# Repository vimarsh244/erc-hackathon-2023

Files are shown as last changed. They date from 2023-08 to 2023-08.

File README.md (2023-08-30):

# ERC Hackathon 2023 submission

### Mechanical

**Design**:

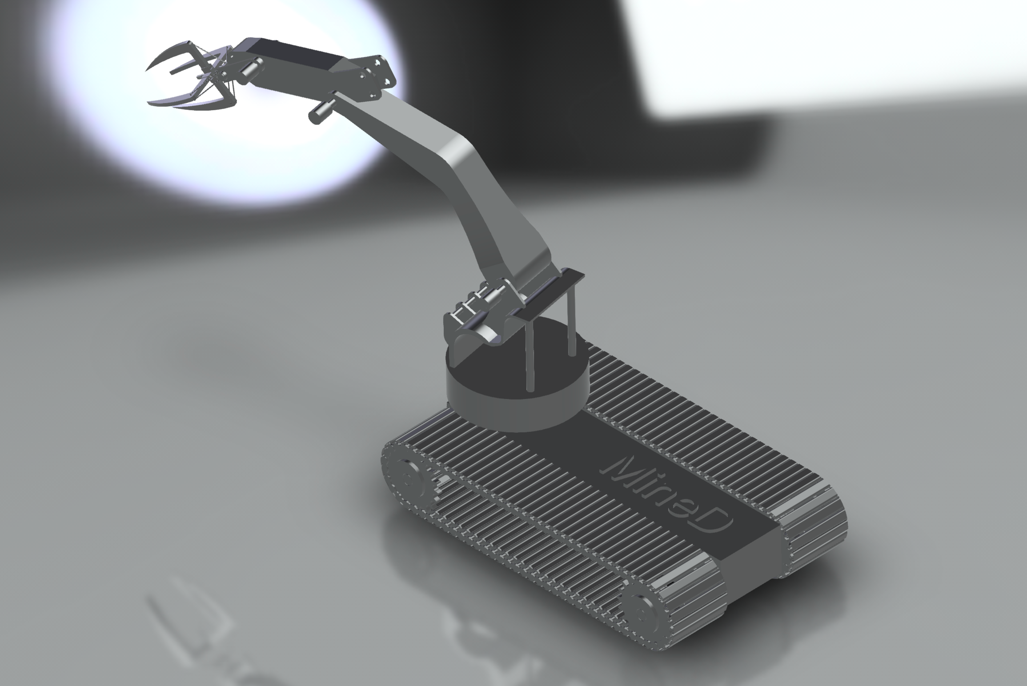
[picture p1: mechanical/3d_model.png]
3D model render


Model files can be found in the `mechanical/` directory or https://a360.co/45wuxL5

**Ansys Analysis**:

Report can be found [here](mechanical/ansys%20analysis/ERC%20HACK%20ANSYS%20MINED.pdf)

### Electronics

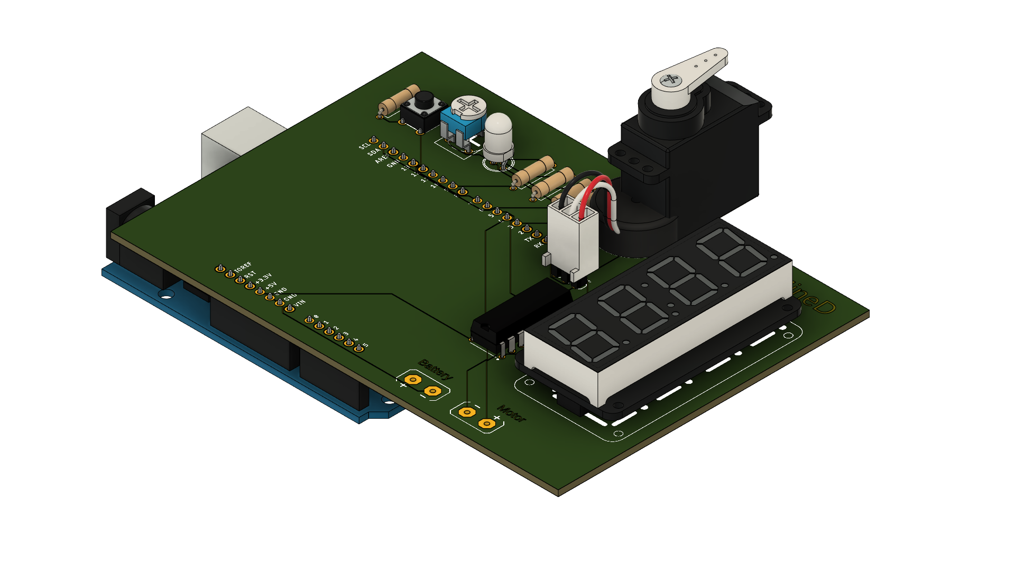
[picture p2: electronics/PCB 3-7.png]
PCB Design Sample


Part 1:

[link](https://www.tinkercad.com/things/8tS4cQEKOlx?sharecode=zMyGMb17AG04Dq2QzwaMsAUVSxyepGBn6ncqBjoWyT0)

The differential drive mechanism is a simple 4wd that takes in (linear.x and angular.z) from ROS controller which will accordingly turn the motors.

Part 2:

[link](https://www.tinkercad.com/things/2AzpW1k3oru?sharecode=b2Rh3jejDMBBp6OE0veHATIasINy7RtwA5-mOQYV0L8)

Part 3-6:

[link](https://www.tinkercad.com/things/doNj9fPPetp?sharecode=6bNxCSpgDcdtsFkDNGaQSvCr4-Utx1kQABxrum8ldWc)

Combined all tasks in one circuit.

#### Coil Mechanism

The Sinusoidal wave produced will be connected to a copper coil (basically an inductor). Another copper coil will be receiving the voltage. When connected across a capacitor and near a mine, due to metal eddy currents, there will be changes across voltage in capacitor measured by Arduino.

#### PCBs

The necessary PCBs can be fouond in the `electronics/` directory.

### Automation

**Color Detection**

Cone detection as follows:
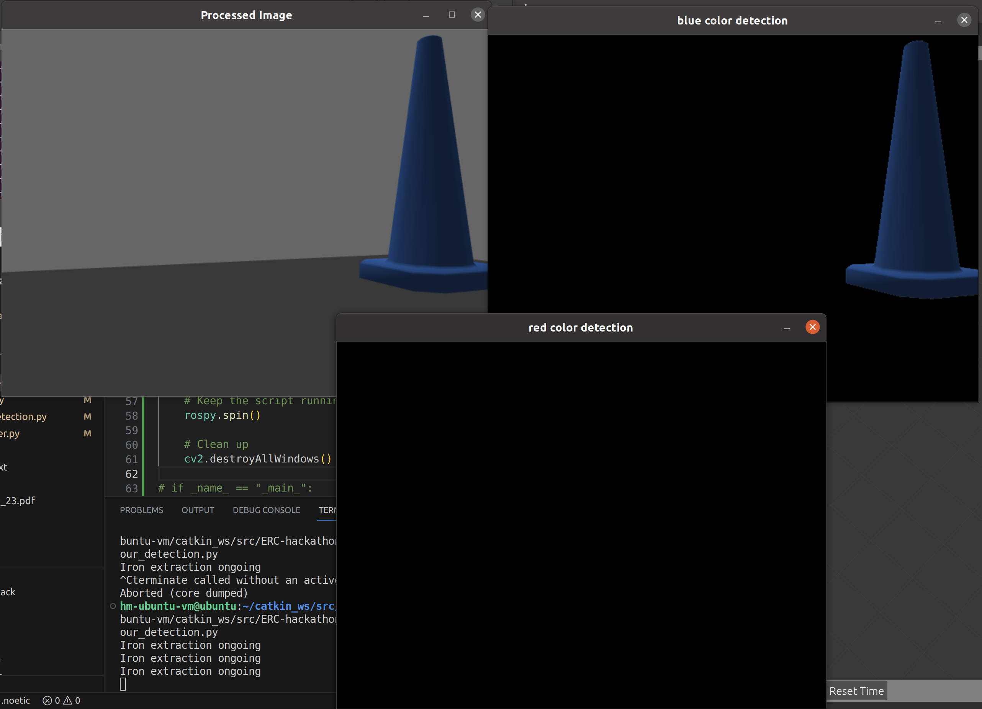
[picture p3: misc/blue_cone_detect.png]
Cone Detection


**Path Planning**

Example path
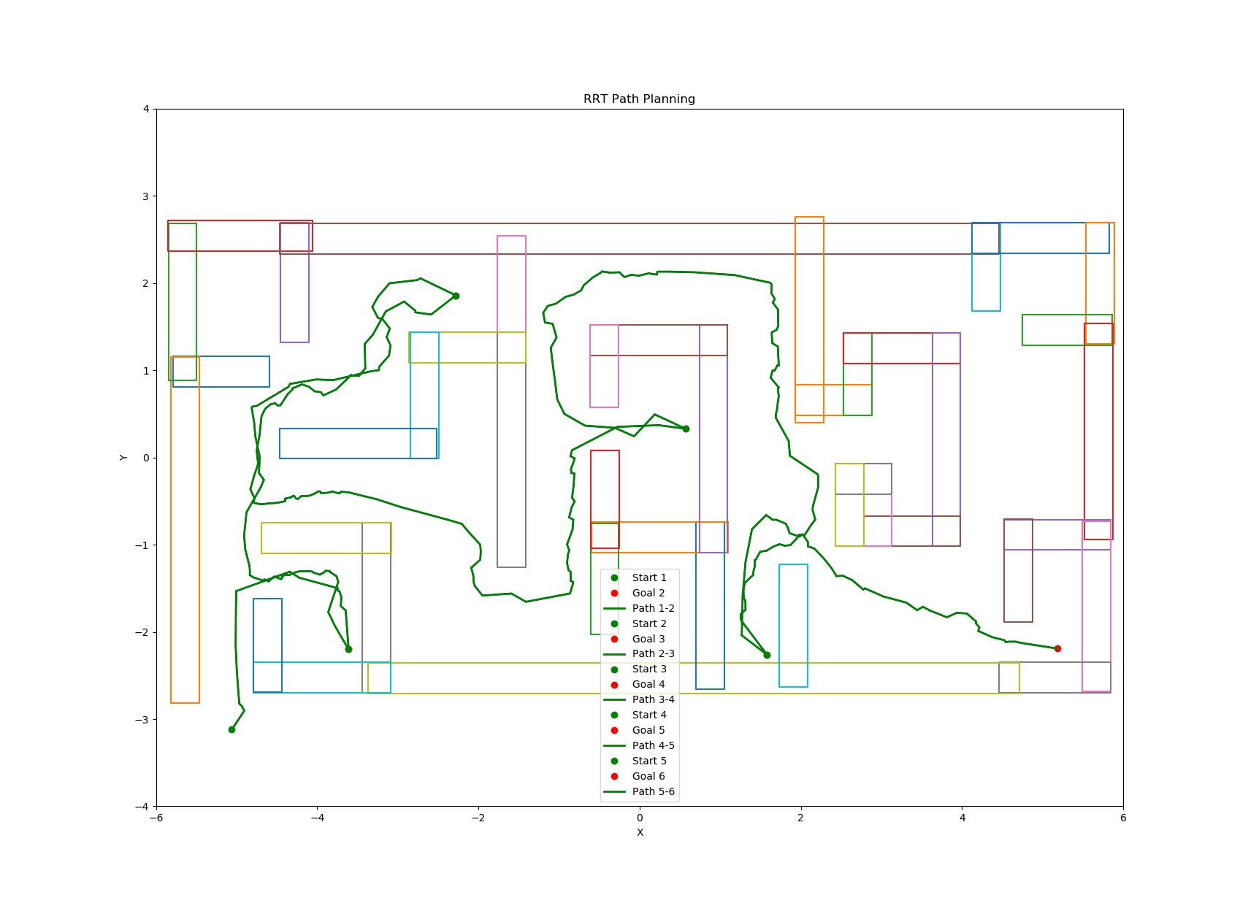
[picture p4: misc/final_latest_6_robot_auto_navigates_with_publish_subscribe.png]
Path Planning Algorithm


Used RRT to create a path, also edited the `obstacle_detection.py` for path to be far away from walls, so that robot doesn't crash with it.

**Controller**

Simple controller for robot to navigate along the planned path. `controller.py`

[demo video of robot moving](misc/final_vid_of_robo_navigating.mp4)

**Others**

run `catkin_make` after cloning in the `~/catkin_ws/src` directory.

Path planner uses RRT to make calculate a path which goes over all points.

`roslaunch robotics_hackathon_automation automation_task.launch`

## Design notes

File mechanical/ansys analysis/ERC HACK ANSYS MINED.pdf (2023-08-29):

# Project*

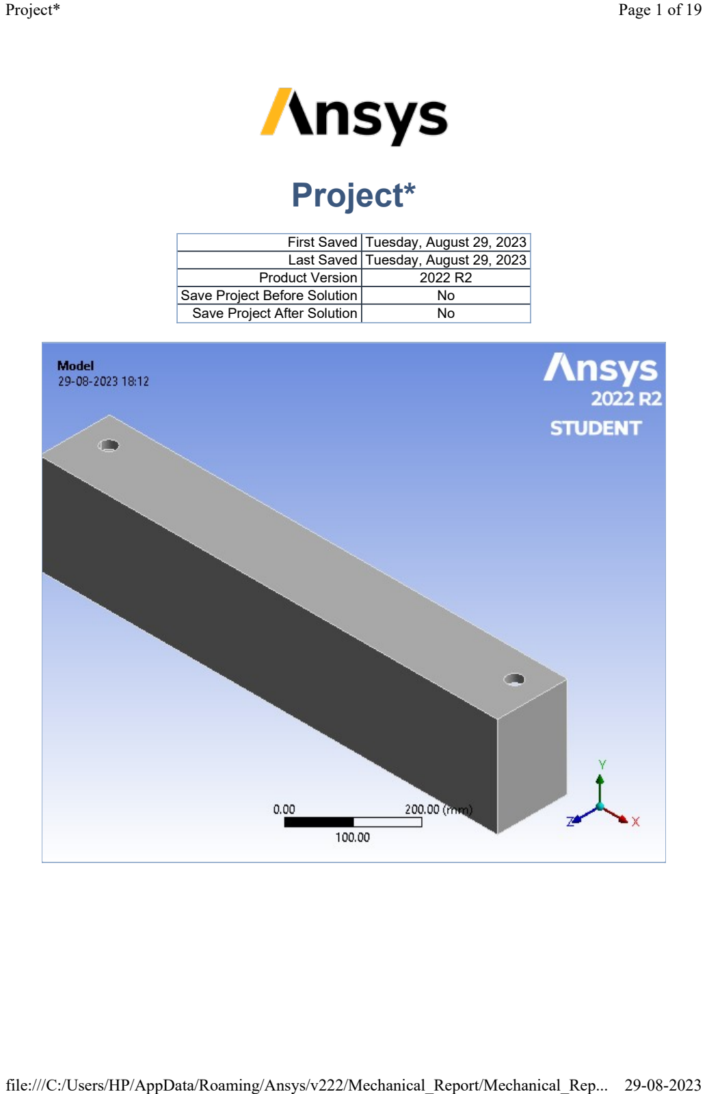
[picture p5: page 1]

First Saved | Tuesday, August 29, 2023
Last Saved | Tuesday, August 29, 2023
Product Version | 2022 R2
Save Project Before Solution | No
Save Project After Solution | No
Project* | Page 1 of 19

file:///C:/Users/HP/AppData/Roaming/Ansys/v222/Mechanical_Report/Mechanical_Rep... 29-08-2023

# Contents

l Units

l Model (A4)
¡ Geometry Imports
n Geometry Import (A3)
¡ Geometry
n Chassie_simplified v0[1]-FreeParts|Body1 ¡ Materials
¡ Coordinate Systems
¡ Mesh
n Mesh Controls
¡ Static Structural (A5)
n Analysis Settings
n Standard Earth Gravity
n Loads
n Solution (A6)
n Solution Information
n Results
n Stress Tool
n Safety Factor

l Material Data
¡ Aluminum Alloy

# Units

TABLE 1

# Model (A4)

TABLE 2
Model (A4) > Geometry Imports

TABLE 3
Model (A4) > Geometry Imports > Geometry Import (A3)
Unit System | Metric (mm, kg, N, s, mV, mA) Degrees rad/s Celsius
Angle | Degrees
Rotational Velocity | rad/s
Temperature | Celsius
Object Name | Geometry Imports
State | Solved
Object Name | Geometry Import (A3)
State | Solved
Definition
Source | C:\Users\HP\Downloads\Chassie_simplified v0[1].step
Type | Step
Basic Geometry Options
Solid Bodies | Yes
Project* | Page 2 of 19

Surface Bodies | Yes
Line Bodies | No
Parameters | Independent
Parameter Key | ANS;DS
Attributes | No
Named Selections | No
Material Properties | No
Advanced Geometry Options
Use Associativity | Yes
Coordinate Systems | No
Reader Mode Saves Updated File | No
Use Instances | Yes
Smart CAD Update | Yes
Compare Parts On Update | No
Analysis Type | 3-D
Mixed Import Resolution | None
Import Facet Quality | Source
Clean Bodies On Import | No
Stitch Surfaces On Import | None
Decompose Disjoint Geometry | Yes
Enclosure and Symmetry Processing | Yes

## Geometry

TABLE 4
Model (A4) > Geometry
Object Name | Geometry
State | Fully Defined
Definition
Source | C:\Users\HP\Downloads\Chassie_simplified v0[1].step
Type | Step
Length Unit | Millimeters
Element Control | Program Controlled
Display Style | Body Color
Bounding Box
Length X | 943.25 mm
Length Y | 205.8 mm
Length Z | 144.49 mm
Properties
Volume | 8.1476e+006 mm³
Mass | 22.569 kg
Scale Factor Value | 1.
Statistics
Bodies | 1
Active Bodies | 1
Nodes | 42084
Elements | 24293
Mesh Metric | None
Update Options
Assign Default Material | No
Basic Geometry Options
Solid Bodies | Yes
Project* | Page 3 of 19

TABLE 5
Model (A4) > Geometry > Parts
Surface Bodies | Yes
Line Bodies | No
Parameters | Independent
Parameter Key | ANS;DS
Attributes | No
Named Selections | No
Material Properties | No
Advanced Geometry Options
Use Associativity | Yes
Coordinate Systems | No
Reader Mode Saves Updated File | No
Use Instances | Yes
Smart CAD Update | Yes
Compare Parts On Update | No
Analysis Type | 3-D
Mixed Import Resolution | None
Import Facet Quality | Source
Clean Bodies On Import | No
Stitch Surfaces On Import | None
Decompose Disjoint Geometry | Yes
Enclosure and Symmetry Processing | Yes
Object Name | Chassie_simplified v0[1]-FreeParts|Body1
State | Meshed
Graphics Properties
Visible | Yes
Transparency | 1
Definition
Suppressed | No
Stiffness Behavior | Flexible
Coordinate System | Default Coordinate System
Reference Temperature | By Environment
Treatment | None
Material
Assignment | Aluminum Alloy
Nonlinear Effects | Yes
Thermal Strain Effects | Yes
Bounding Box
Length X | 943.25 mm
Length Y | 205.8 mm
Length Z | 144.49 mm
Properties
Volume | 8.1476e+006 mm³
Mass | 22.569 kg
Centroid X | 471.63 mm
Centroid Y | 102.9 mm
Centroid Z | 93.244 mm
Moment of Inertia Ip1 | 1.8503e+005 kg·mm²
Moment of Inertia Ip2 | 1.9972e+006 kg·mm²
Moment of Inertia Ip3 | 2.0885e+006 kg·mm²
Project* | Page 4 of 19

TABLE 6
Model (A4) > Materials

Statistics
Nodes | 42084
Elements | 24293
Mesh Metric | None
Object Name | Materials
State | Fully Defined
Statistics
Materials | 1
Material Assignments | 0

## Coordinate Systems

TABLE 7
Model (A4) > Coordinate Systems > Coordinate System
Object Name | Global Coordinate System
State | Fully Defined
Definition
Type | Cartesian
Coordinate System ID | 0.
Origin
Origin X | 0. mm
Origin Y | 0. mm
Origin Z | 0. mm
Directional Vectors
X Axis Data | [ 1. 0. 0. ]
Y Axis Data | [ 0. 1. 0. ]
Z Axis Data | [ 0. 0. 1. ]

## Mesh

TABLE 8
Model (A4) > Mesh
Object Name | Mesh
State | Solved
Display
Display Style Use Geometry Setting Defaults
Physics Preference | Mechanical
Element Order | Program Controlled
Element Size | Default
Sizing
Use Adaptive Sizing | Yes
Resolution | Default (2)
Mesh Defeaturing | Yes
Defeature Size | Default
Transition | Fast
Span Angle Center | Coarse
Initial Size Seed | Assembly
Bounding Box Diagonal | 976.19 mm
Project* | Page 5 of 19

TABLE 9
Model (A4) > Mesh > Mesh Controls

FIGURE 1
Model (A4) > Mesh > Figure
Average Surface Area | 66413 mm²
Minimum Edge Length | 17.15 mm
Quality
Check Mesh Quality | Yes, Errors
Error Limits | Aggressive Mechanical
Target Element Quality | Default (5.e-002)
Smoothing | Medium
Mesh Metric | None
Inflation
Use Automatic Inflation | None
Inflation Option | Smooth Transition
Transition Ratio | 0.272
Maximum Layers | 5
Growth Rate | 1.2
Inflation Algorithm | Pre
View Advanced Options | No
Advanced
Number of CPUs for Parallel Part Meshing | Program Controlled
Straight Sided Elements | No
Rigid Body Behavior | Dimensionally Reduced
Triangle Surface Mesher | Program Controlled
Topology Checking | Yes
Pinch Tolerance | Please Define
Generate Pinch on Refresh | No
Statistics
Nodes | 42084
Elements | 24293
Object Name | Patch Conforming Method | Body Sizing
State | Fully Defined
Scope
Scoping Method | Geometry Selection
Geometry | 1 Body
Definition
Suppressed | No
Method | Tetrahedrons
Algorithm | Patch Conforming
Element Order | Use Global Setting
Type | | Element Size
Element Size | | 15.0 mm
Advanced
Defeature Size | Default
Behavior | Soft
Project* | Page 6 of 19

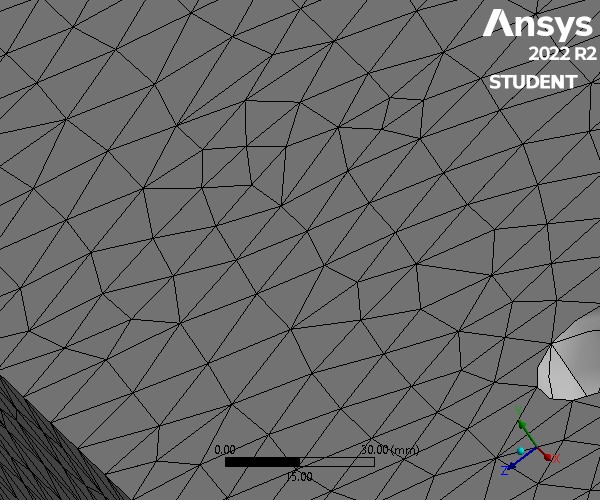
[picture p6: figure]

# Static Structural (A5)

TABLE 10
Model (A4) > Analysis

TABLE 11
Model (A4) > Static Structural (A5) > Analysis Settings
Object Name | Static Structural (A5)
State | Solved
Definition
Physics Type | Structural
Analysis Type | Static Structural
Solver Target | Mechanical APDL
Options
Environment Temperature | 22. °C
Generate Input Only | No
Object Name | Analysis Settings
State | Fully Defined
Step Controls
Number Of Steps | 1.
Current Step Number | 1.
Step End Time | 1. s
Project* | Page 7 of 19

TABLE 12

Auto Time Stepping | Program Controlled Solver Controls
Solver Type | Program Controlled
Weak Springs | Off
Solver Pivot Checking | Program Controlled
Large Deflection | Off
Inertia Relief | Off
Quasi-Static Solution | Off
Rotordynamics Controls
Coriolis Effect | Off
Restart Controls
Generate Restart Points | Program Controlled
Retain Files After Full Solve | No
Combine Restart Files | Program Controlled
Nonlinear Controls
Newton-Raphson Option | Program Controlled
Force Convergence | Program Controlled
Moment Convergence | Program Controlled
Displacement Convergence | Program Controlled
Rotation Convergence | Program Controlled
Line Search | Program Controlled
Stabilization | Program Controlled
Advanced
Inverse Option | No
Contact Split (DMP) | Off
Output Controls
Stress | Yes
Surface Stress | No
Back Stress | No
Strain | Yes
Contact Data | Yes
Nonlinear Data | No
Nodal Forces | No
Volume and Energy | Yes
Euler Angles | Yes
General Miscellaneous | No
Contact Miscellaneous | No
Store Results At | All Time Points
Result File Compression | Program Controlled
Analysis Data Management
Solver Files Directory | C:\Users\HP\AppData\Local\Temp\WB_HP_8532_4\wbnew_files\dp0 \SYS\MECH\
Future Analysis | None
Scratch Solver Files Directory
Save MAPDL db | No
Contact Summary | Program Controlled
Delete Unneeded Files | Yes
Nonlinear Solution | No
Solver Units | Active System
Solver Unit System | nmm
Project* | Page 8 of 19

Model (A4) > Static Structural (A5) > Accelerations

FIGURE 2
Model (A4) > Static Structural (A5) > Standard Earth Gravity

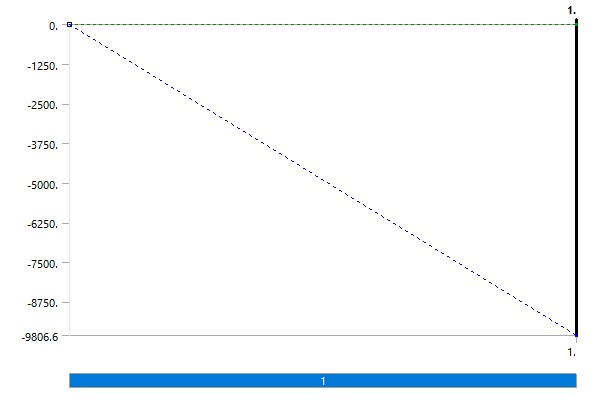
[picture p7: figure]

TABLE 13
Model (A4) > Static Structural (A5) > Loads
Object Name | Standard Earth Gravity
State | Fully Defined
Scope
Geometry | All Bodies
Definition
Coordinate System | Global Coordinate System
X Component | 0. mm/s² (ramped)
Y Component | 0. mm/s² (ramped)
Z Component | -9806.6 mm/s² (ramped)
Suppressed | No
Direction | -Z Direction
Object Name | Force | Fixed Support
State | Fully Defined
Scope
Scoping Method | Geometry Selection
Geometry | 1 Face
Definition
Type | Force | Fixed Support
Define By | Vector
Applied By | Surface Effect
Magnitude | -500. N (ramped)
Direction | Defined
Project* | Page 9 of 19

FIGURE 3
Model (A4) > Static Structural (A5) > Force
Suppressed | No

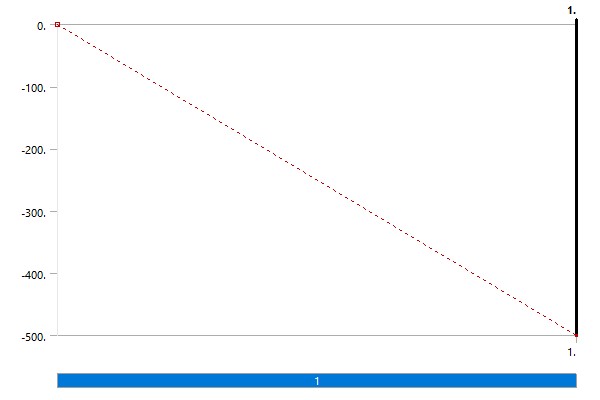
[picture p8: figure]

## Solution (A6)

TABLE 14
Model (A4) > Static Structural (A5) > Solution

TABLE 15
Model (A4) > Static Structural (A5) > Solution (A6) > Solution Information
Object Name | Solution (A6)
State | Solved
Adaptive Mesh Refinement
Max Refinement Loops | 1.
Refinement Depth | 2.
Information
Status | Done
MAPDL Elapsed Time | 11. s
MAPDL Memory Used | 755. MB
MAPDL Result File Size | 15.75 MB
Post Processing
Beam Section Results | No
On Demand Stress/Strain | No
Object Name | Solution Information
State | Solved
Solution Information
Solution Output | Solver Output
Project* | Page 10 of 19

TABLE 16
Model (A4) > Static Structural (A5) > Solution (A6) > Results

FIGURE 4
Model (A4) > Static Structural (A5) > Solution (A6) > Total Deformation
Newton-Raphson Residuals | 0
Identify Element Violations | 0
Update Interval | 2.5 s
Display Points | All
FE Connection Visibility
Activate Visibility | Yes
Display | All FE Connectors
Draw Connections Attached To | All Nodes
Line Color | Connection Type
Visible on Results | No
Line Thickness | Single
Display Type | Lines
Object Name | Total Deformation | Equivalent Elastic Strain
State | Solved
Scope
Scoping Method | Geometry Selection
Geometry | All Bodies
Definition
Type | Total Deformation | Equivalent Elastic Strain
By | Time
Display Time | Last
Calculate Time History | Yes
Identifier
Suppressed | No
Results
Minimum | 0. mm | 2.4968e-008 mm/mm
Maximum | 6.1645e-004 mm | 1.7105e-006 mm/mm
Average | 1.5366e-004 mm | 5.4677e-007 mm/mm
Minimum Occurs On | Chassie_simplified v0[1]-FreeParts|Body1
Maximum Occurs On | Chassie_simplified v0[1]-FreeParts|Body1
Information
Time | 1. s
Load Step | 1
Substep | 1
Iteration Number | 1
Integration Point Results
Display Option | Averaged
Average Across Bodies | No
Project* | Page 11 of 19

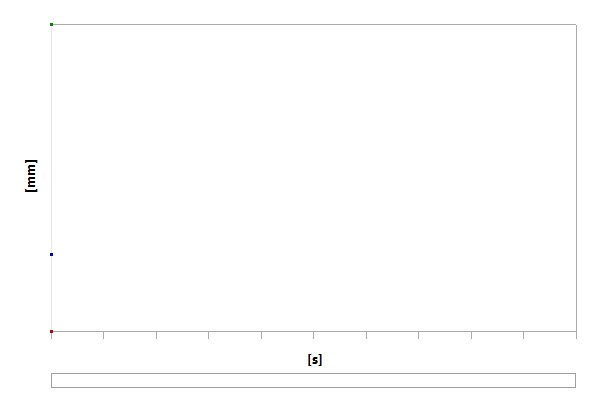
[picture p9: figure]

TABLE 17
Model (A4) > Static Structural (A5) > Solution (A6) > Total Deformation

FIGURE 5
Model (A4) > Static Structural (A5) > Solution (A6) > Total Deformation > Figure
Time [s] | Minimum [mm] | Maximum [mm] | Average [mm]
1. | 0. | 6.1645e-004 | 1.5366e-004
Project* | Page 12 of 19

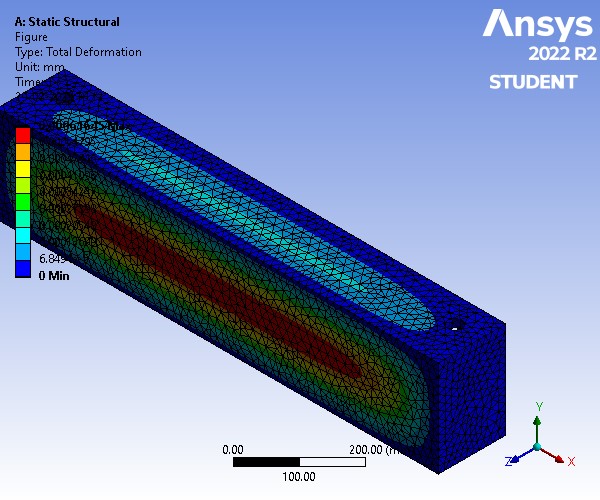
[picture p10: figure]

FIGURE 6
Model (A4) > Static Structural (A5) > Solution (A6) > Equivalent Elastic Strain
Project* | Page 13 of 19

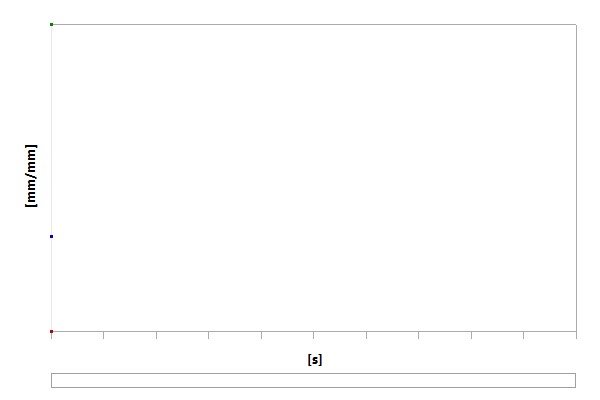
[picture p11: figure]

TABLE 18
Model (A4) > Static Structural (A5) > Solution (A6) > Equivalent Elastic Strain

FIGURE 7
Model (A4) > Static Structural (A5) > Solution (A6) > Equivalent Elastic Strain > Figure
Time [s] | Minimum [mm/mm] | Maximum [mm/mm] | Average [mm/mm]
1. | 2.4968e-008 | 1.7105e-006 | 5.4677e-007
Project* | Page 14 of 19

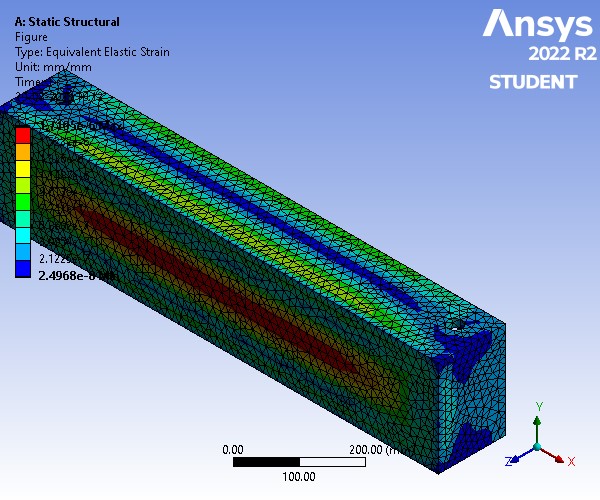
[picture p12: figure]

TABLE 19
Model (A4) > Static Structural (A5) > Solution (A6) > Stress Safety Tools

TABLE 20
Model (A4) > Static Structural (A5) > Solution (A6) > Stress Tool > Results
Object Name | Stress Tool
State | Solved
Definition
Theory | Max Equivalent Stress
Stress Limit Type | Tensile Yield Per Material
Object Name | Safety Factor
State | Solved
Scope
Scoping Method | Geometry Selection
Geometry | All Bodies
Definition
Type | Safety Factor
By | Time
Display Time | Last
Calculate Time History | Yes
Identifier
Suppressed | No
Integration Point Results
Project* | Page 15 of 19

FIGURE 8
Model (A4) > Static Structural (A5) > Solution (A6) > Stress Tool > Safety Factor

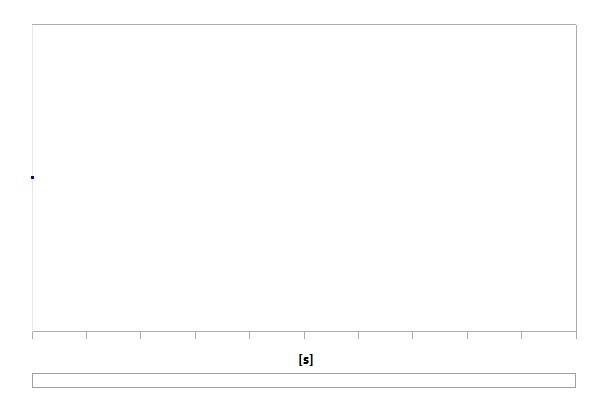
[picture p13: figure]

TABLE 21
Model (A4) > Static Structural (A5) > Solution (A6) > Stress Tool > Safety Factor

FIGURE 9
Model (A4) > Static Structural (A5) > Solution (A6) > Stress Tool > Safety Factor > Figure
Display Option | Averaged
Average Across Bodies | No
Results
Minimum | > 10
Minimum Occurs On | Chassie_simplified v0[1]-FreeParts|Body1
Information
Time | 1. s
Load Step | 1
Substep | 1
Iteration Number | 1
Time [s] | Minimum | Maximum | Average
1. | 15. | 15. | 15.
Project* | Page 16 of 19

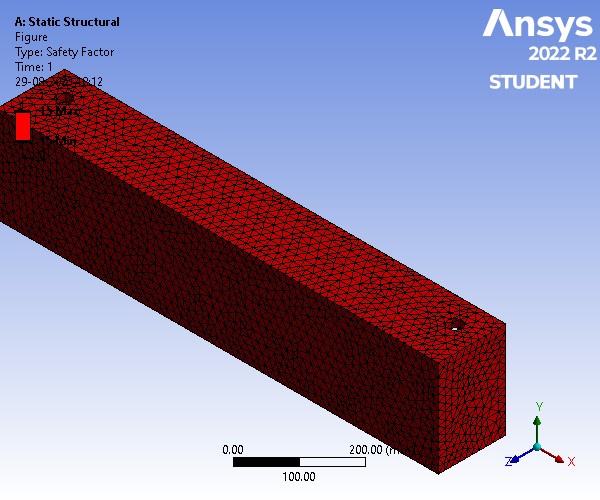
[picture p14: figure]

# Material Data

## Aluminum Alloy

TABLE 22
Aluminum Alloy > Constants

TABLE 23
Aluminum Alloy > Color

TABLE 24
Aluminum Alloy > Compressive Ultimate Strength

TABLE 25
Aluminum Alloy > Compressive Yield Strength
Density | 2.77e-006 kg mm^-3
Coefficient of Thermal Expansion | 2.3e-005 C^-1
Specific Heat | 8.75e+005 mJ kg^-1 C^-1
Red | Green | Blue
138 | 104 | 46

Compressive Ultimate Strength MPa 0

Project* | Page 17 of 19

TABLE 26
Aluminum Alloy > Tensile Yield Strength

TABLE 27
Aluminum Alloy > Tensile Ultimate Strength

TABLE 28
Aluminum Alloy > Isotropic Secant Coefficient of Thermal Expansion

TABLE 29
Aluminum Alloy > Isotropic Thermal Conductivity

TABLE 30
Aluminum Alloy > S-N Curve

Compressive Yield Strength MPa 280

Tensile Yield Strength MPa 280

Tensile Ultimate Strength MPa 310

Zero-Thermal-Strain Reference Temperature C 22

Thermal Conductivity W mm^-1 C^-1 | Temperature C
0.114 -100
0.144 0
0.165 100
0.175 200
Alternating Stress MPa | Cycles | R-Ratio
275.8 | 1700 | -1
241.3 | 5000 | -1
206.8 | 34000 | -1
172.4 | 1.4e+005 | -1
137.9 | 8.e+005 | -1
117.2 | 2.4e+006 | -1
89.63 | 5.5e+007 | -1
82.74 | 1.e+008 | -1
170.6 | 50000 | -0.5
139.6 | 3.5e+005 | -0.5
108.6 | 3.7e+006 | -0.5
87.91 | 1.4e+007 | -0.5
77.57 | 5.e+007 | -0.5
72.39 | 1.e+008 | -0.5
144.8 | 50000 | 0
120.7 | 1.9e+005 | 0
103.4 | 1.3e+006 | 0
93.08 | 4.4e+006 | 0
86.18 | 1.2e+007 | 0
72.39 | 1.e+008 | 0
74.12 | 3.e+005 | 0.5
70.67 | 1.5e+006 | 0.5
66.36 | 1.2e+007 | 0.5
62.05 | 1.e+008 | 0.5
Project* | Page 18 of 19

TABLE 31
Aluminum Alloy > Isotropic Resistivity

TABLE 32
Aluminum Alloy > Isotropic Elasticity

TABLE 33
Aluminum Alloy > Isotropic Relative Permeability
Resistivity ohm mm | Temperature C
2.43e-005 | 0
2.67e-005 | 20
3.63e-005 | 100
Young's Modulus MPa | Poisson's Ratio | Bulk Modulus MPa | Shear Modulus MPa | Temperature C
71000 | 0.33 | 69608 | 26692

Relative Permeability
1
Project* | Page 19 of 19

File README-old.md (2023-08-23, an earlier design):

# ERC Hackathon 2023

This repository contains all of the instructions and files required to solve the Electronics and Robotics Club's Hackathon 2023.<br><br>
The hackathon is focused on the design of an **autonomous land-mine detection and extraction robot**. Your team has to provide a solution consisting of the mechanical design, electronics interfacing and an implementation of autonomous behavior. All three tasks are linked to the same final goal and yet can be completed independently.<br><br>
The registration form link can be found [here](https://forms.gle/wjGYFgRjN8xn6po36).<br><br>
The tentative deadline for submission is **11:59 P.M.** on **21st August**<br><br>
In case of any queries contact:<br><br>
Arjun Puthli: 9594333307<br>
Shantanu Deshmuk: 8983172114<br>
Aasim Sayyed: 7058577593<br>
Aditya Kurande: 7722030520<br>
Ishan Gokhale: 7057401698

#### Teams with complete submissions will be inducted into ERC!
___

## Problem Statement

The detailed problem statement can be found [here](./erc_hackathon_23.pdf)<br><br>
Robotics as a domain can be divided as:<br>
1. Design (Mechanical and Electronics: What components and sensors is the robot made of)
2. Perception (Obtaining information about the robot's environment using the sensors)
3. Planning (Calculating a series of behavious to execute based on what is desired and what the environment looks like)
4. Control (Executing the planned behaviours and ensuring the goal is actually achieved via the robot's actuators)
<br>
All four are closely linked to each other and most autonomous robotic systems will need all four.<br><br>
The hackathon contains atleast one task from each broad divison. However this hackathon is structured such that every task is independent of each other. This will not be the case in a real world robot, but it is a good place to dive into designing a functional robotic system.<br>

___

## Setting up the environment

### Mechanical Design and Analysis
Use [Fusion 360](https://www.autodesk.in/products/fusion-360/education) for CAD modelling and [ANSYS](https://www.youtube.com/playlist?list=PL0Ya8d8RGCTqSaM6GbGHXqAUq1ga7-N__) for structural analysis.

### Electronics Design and Interfacing
The circuit simulation is to be done using the [TinkerCad](https://www.tinkercad.com/) simulator which does not require any installation. PCB design is to be done using [EAGLE](https://www.autodesk.in/products/eagle/overview). EAGLE is a paid software but is free for students (make use of your BITS mail, since you would have already made an autodesk account for EG).<br><br>
**Important Clarification**: Use an **Arduino Uno** along with other required components for the electronics simulation task.
<br>

### Automation (Perception, Planning and Control)
The following are the system requirements for simulating the automation task:
1. Linux (Ubuntu 20.04 [dual boot](https://itsfoss.com/install-ubuntu-1404-dual-boot-mode-windows-8-81-uefi/) recommended. Refer to problem statement for alternatives.)
2. [ROS Noetic](http://wiki.ros.org/noetic/Installation/Ubuntu#Ubuntu_install_of_ROS_Noetic)
- It is recommended that you install ```ros-noetic-desktop-full``` as it also installs other required packages along with it
3. Gazebo (Not required separately if you have installed ```ros-noetic-desktop-full```)<br>
To verify, use this command:
```
gazebo --version
```
If you are able to see the version, Gazebo is installed.<br><br>
4. TurtleBot3 [Setup manual](https://emanual.robotis.com/docs/en/platform/turtlebot3/simulation/) (**NOTE:** Change kinetic to noetic if you follow the instructions in the link)<br>
<br>

#### Detailed setup instructions for turtlebot3: 
Run the following commands sequentially 
<br>
**Install dependent packages:**
```
sudo apt-get install ros-noetic-joy ros-noetic-teleop-twist-joy \
ros-noetic-teleop-twist-keyboard ros-noetic-laser-proc \
ros-noetic-rgbd-launch ros-noetic-depthimage-to-laserscan \
ros-noetic-rosserial-arduino ros-noetic-rosserial-python \
ros-noetic-rosserial-server ros-noetic-rosserial-client \
ros-noetic-rosserial-msgs ros-noetic-amcl ros-noetic-map-server \
ros-noetic-move-base ros-noetic-urdf ros-noetic-xacro \
ros-noetic-compressed-image-transport ros-noetic-rqt* \
ros-noetic-gmapping ros-noetic-navigation ros-noetic-interactive-markers
```
<br>

**Install turtlebot3:**
```
sudo apt-get install ros-noetic-dynamixel-sdk
```

```
sudo apt-get install ros-noetic-turtlebot3-msgs
```
```
sudo apt-get install ros-noetic-turtlebot3
```
<br>

**Install turtlebot3 simulation package:**<br>
Navigate to your catkin workspace source folder
```
cd ~/catkin_ws/src/
```
Clone the turtlebot3_simulations repo:
```
git clone -b noetic-devel https://github.com/ROBOTIS-GIT/turtlebot3_simulations.git
```
Build your workspace (Note: Most resources including the book by Morgan Quigley use catkin_make instead of catkin build, but make sure you use catkin build instead) 
```
cd ~/catkin_ws && catkin build
```
<br><br>
**Automation task package**<br>
Clone this repository in your catkin workspace source folder.
```
cd ~/catkin_ws/src/
```
```
git clone https://github.com/ERC-BPGC/ERC-hackathon-2023.git
```
The ROS package ```robotics_hackathon_automation``` contains all the files required.<br> 
This completes the environment setup for the autonmation task.

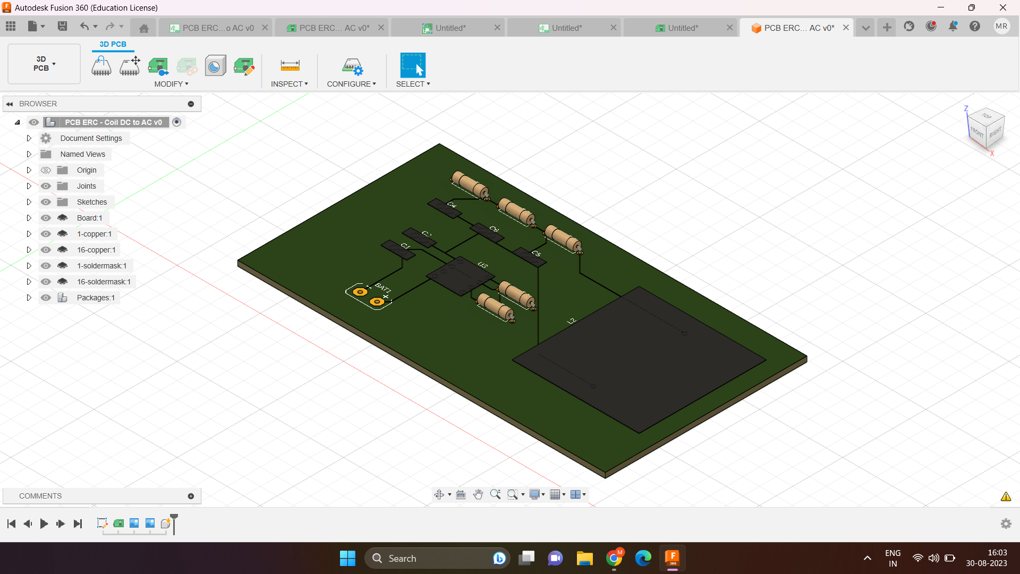
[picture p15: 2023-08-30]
electronics/pcb q2 3d model.png

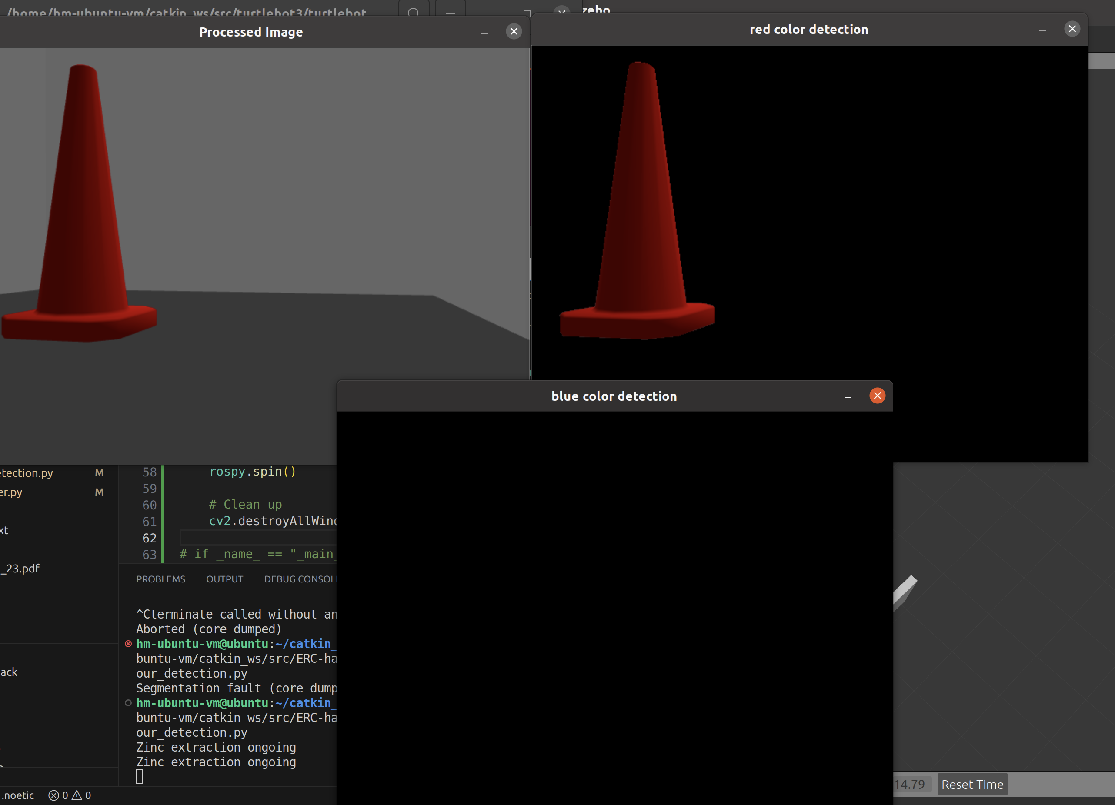
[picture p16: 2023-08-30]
misc/red_detect.png

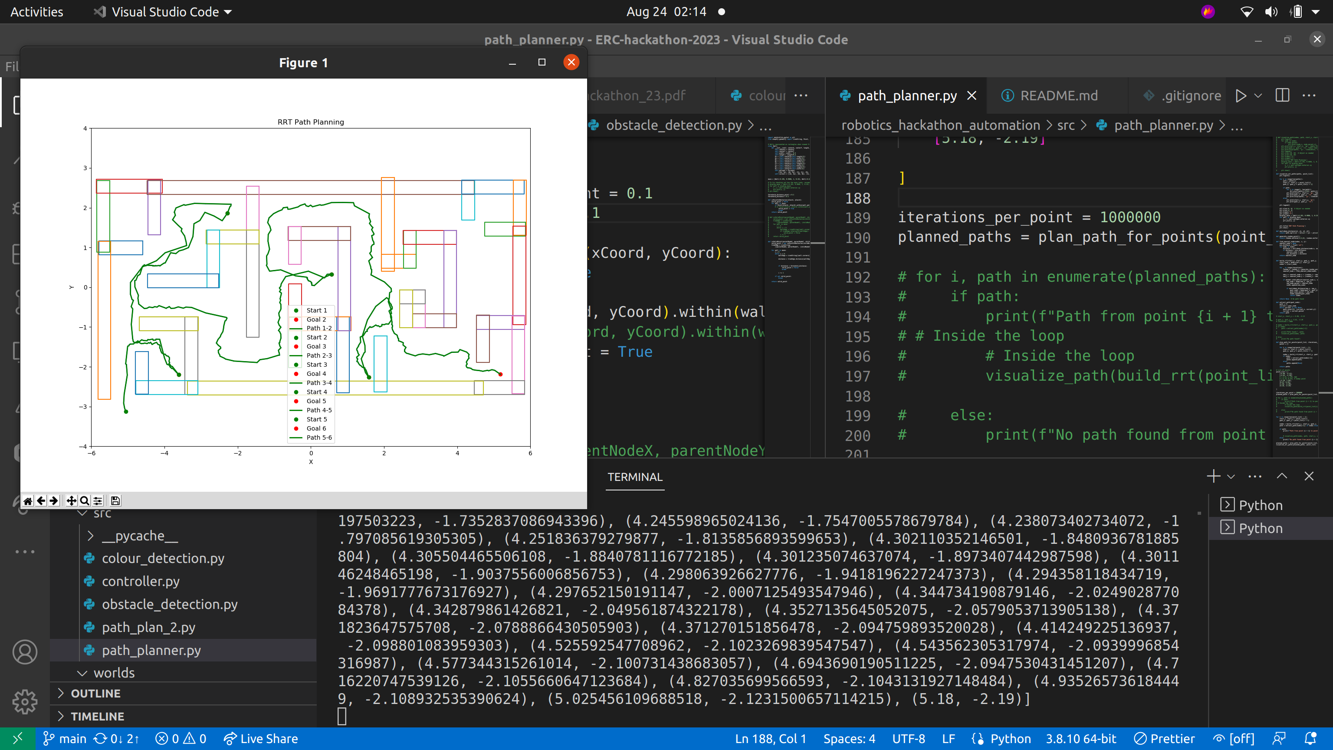
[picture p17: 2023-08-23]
misc/3_visualize.png

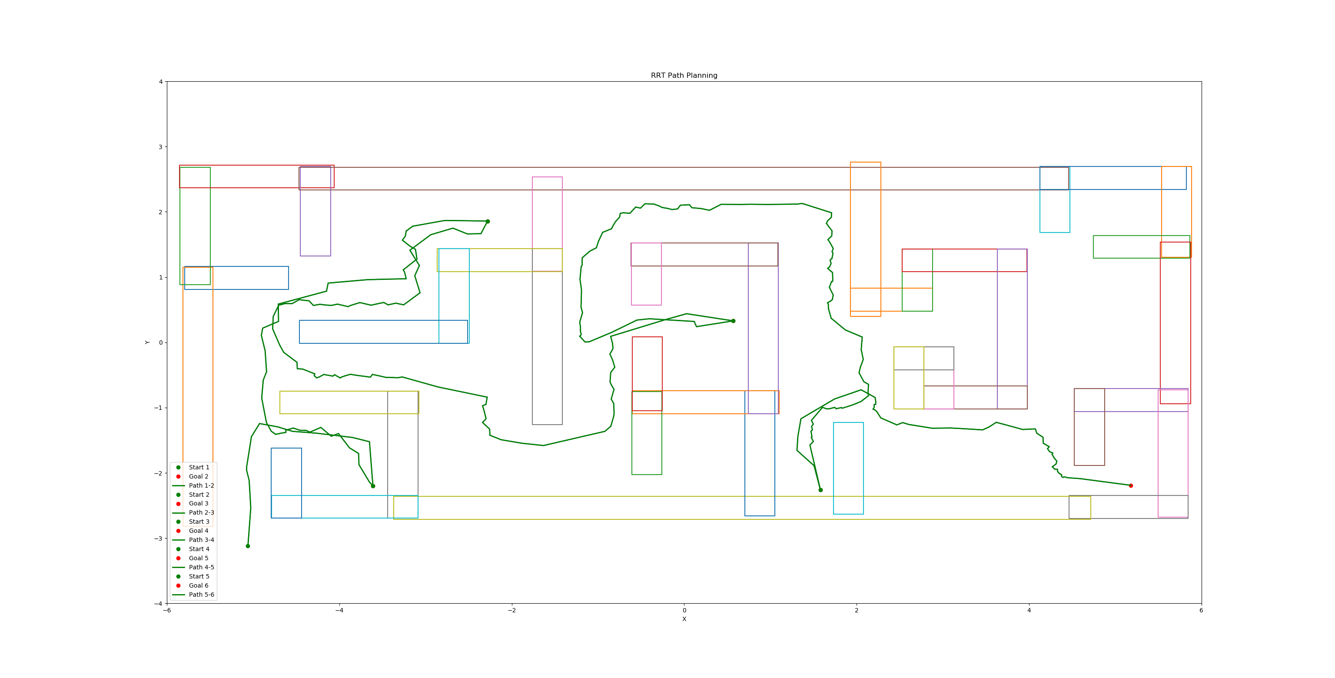
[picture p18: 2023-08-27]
misc/try_4_path_planning.png

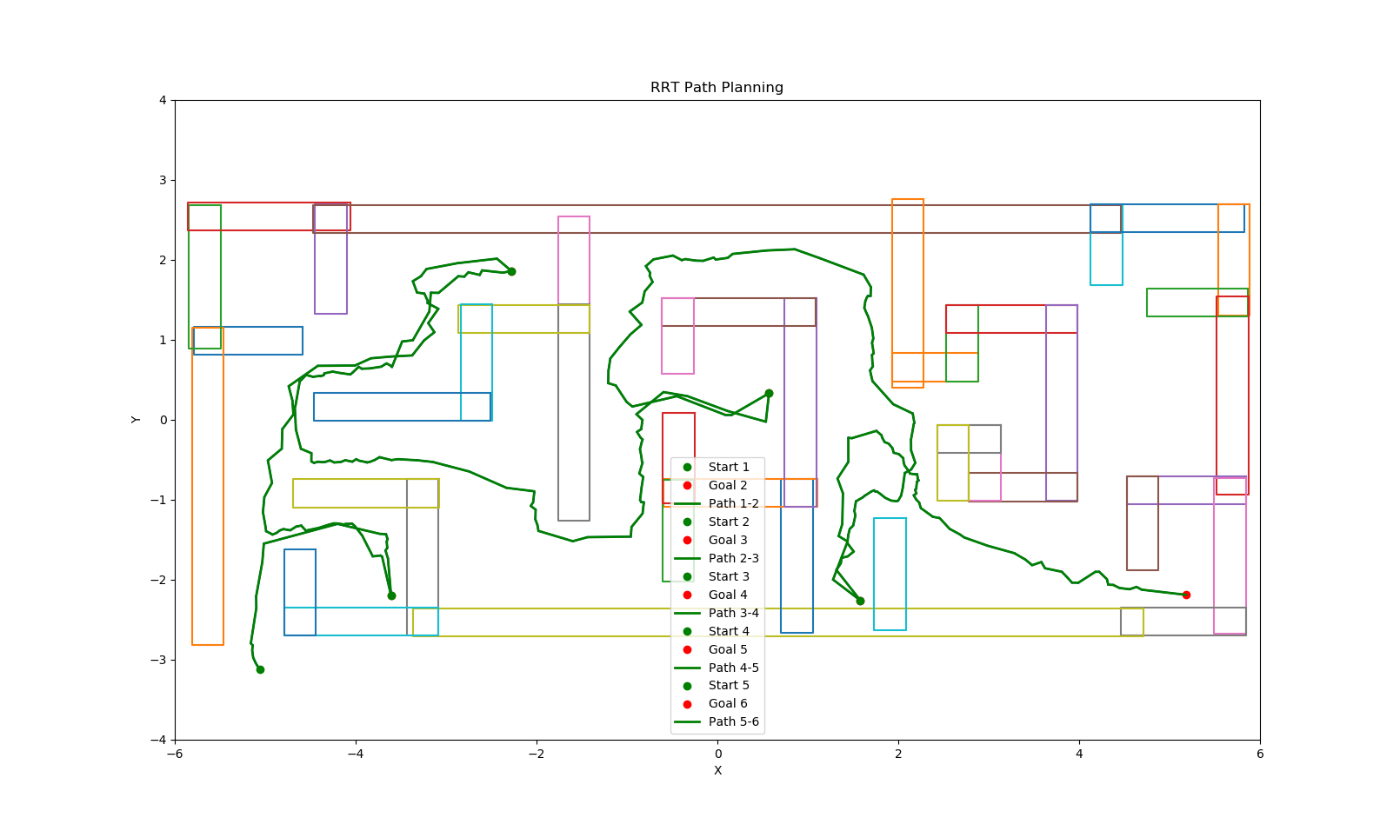
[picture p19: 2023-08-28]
misc/5_try_less_runs_publish.png

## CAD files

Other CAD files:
electronics/PCB ERC - Coil DC to AC v0.f3d

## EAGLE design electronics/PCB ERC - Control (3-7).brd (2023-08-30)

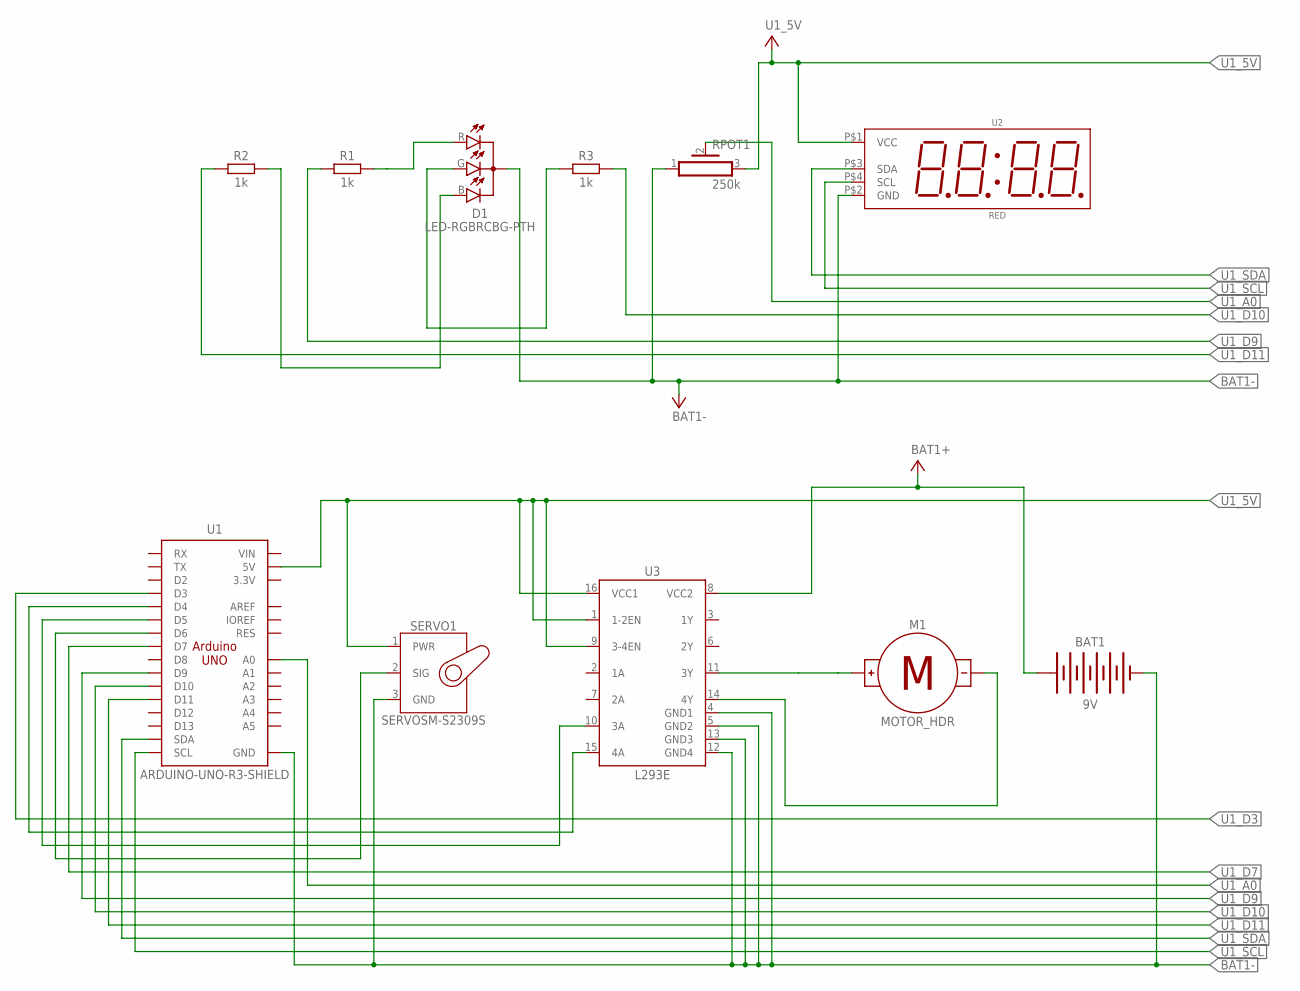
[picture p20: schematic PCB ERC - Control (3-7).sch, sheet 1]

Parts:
BAT1: 9V; BATTERY-GENERIC
D1: LED-RGBRCBG-PTH; LED-RGB-5MM
M1: MOTOR_HDR; MOTOR
R1, R2, R3: 1k; RESAD1016W63L850D250B
RPOT1: 250k; HA-06-SM065
SERVO1: SERVOSM-S2309S; SM-S2309S
U1: ARDUINO-UNO-R3-SHIELD
U2: RED; 7SEG-X4-I2C
U3: L293E; DIP762W53P254L1969H508Q16B

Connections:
BAT1+: BAT1.+, U3.8 (VCC2)
BAT1-: BAT1.-, D1.C, RPOT1.1, SERVO1.3 (GND), U1.GND@0 (GND), U1.GND@1 (GND), U1.GND@2 (GND), U2.P$2 (GND), U3.4 (GND1), U3.5 (GND2), U3.12 (GND4), U3.13 (GND3); also elsewhere on the board
D1_B: D1.B, R2.2
D1_G: D1.G, R3.2
D1_R: D1.R, R1.2
M1_+: M1.+, U3.11 (3Y)
M1_-: M1.-, U3.14 (4Y)
U1_5V: RPOT1.3, SERVO1.1 (PWR), U1.5V, U2.P$1 (VCC), U3.1 (1-2EN), U3.9 (3-4EN), U3.16 (VCC1); also elsewhere on the board
U1_A0: RPOT1.2, U1.A0
U1_D3: U1.D3; also elsewhere on the board
U1_D4: U1.D4, U3.15 (4A)
U1_D5: U1.D5, U3.10 (3A)
U1_D6: SERVO1.2 (SIG), U1.D6
U1_D7: U1.D7; also elsewhere on the board
U1_D9: R1.1, U1.D9
U1_D10: R3.1, U1.D10
U1_D11: R2.1, U1.D11
U1_SCL: U1.SCL, U2.P$4 (SCL)
U1_SDA: U1.SDA, U2.P$3 (SDA)

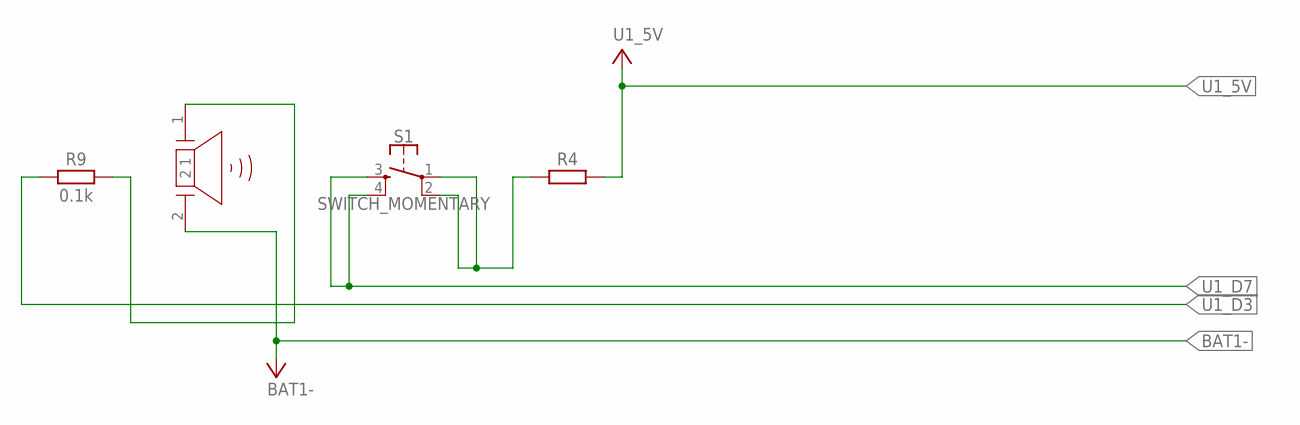
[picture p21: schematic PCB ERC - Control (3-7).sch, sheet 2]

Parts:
PIEZO1: PIEZO
R4: RESISTOR_AXIAL-10.16MM-PITCH; RESAD1016W63L850D250B
R9: 0.1k; RESAD1016W63L850D250B
S1: SWITCH_MOMENTARY; SWITCH-MOMENTARY-PTH-6.5MM

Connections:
BAT1-: PIEZO1.2; also elsewhere on the board
PIEZO1_1: PIEZO1.1, R9.2
S1_1: R4.1, S1.1, S1.2
U1_5V: R4.2; also elsewhere on the board
U1_D3: R9.1; also elsewhere on the board
U1_D7: S1.3, S1.4; also elsewhere on the board

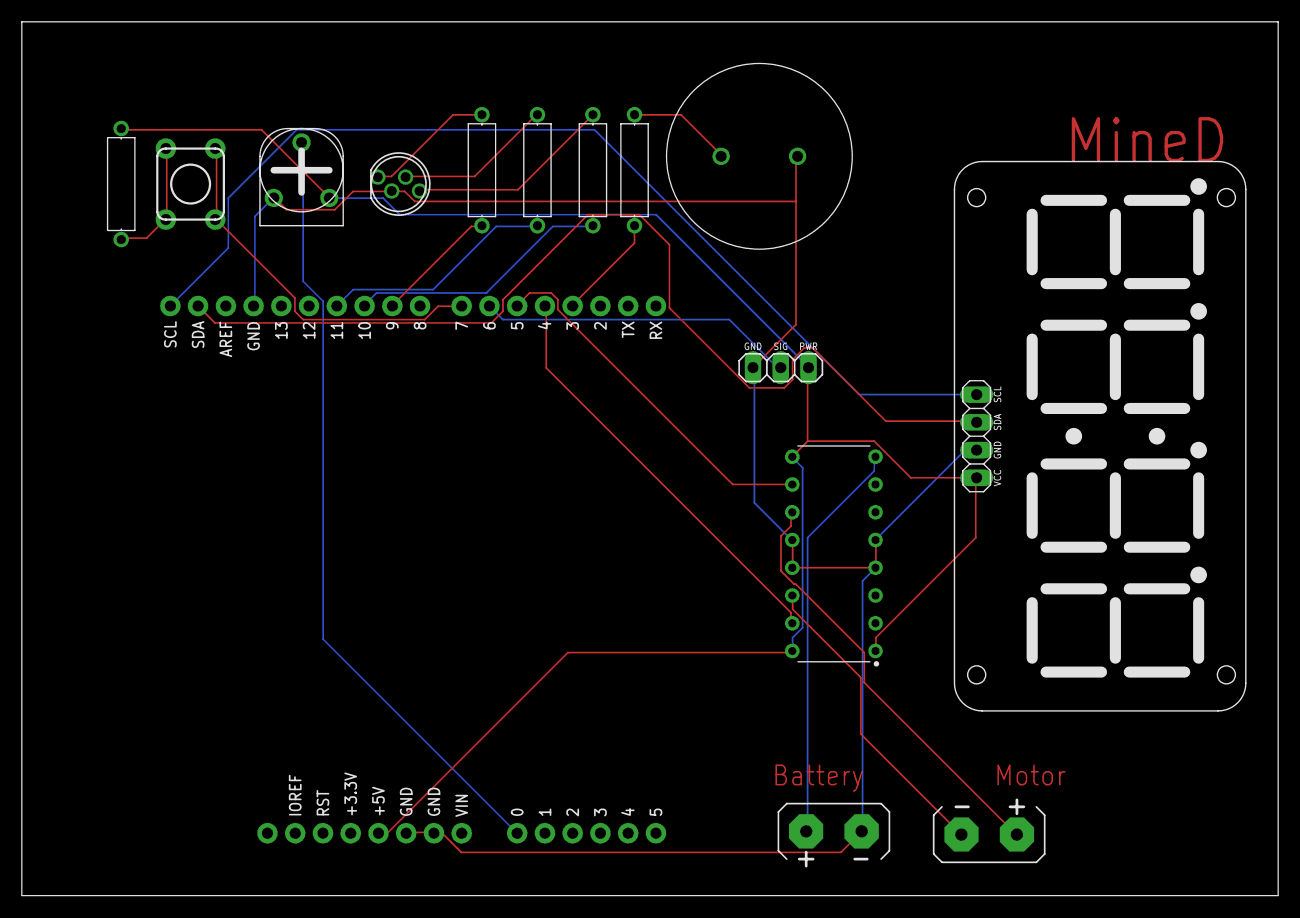
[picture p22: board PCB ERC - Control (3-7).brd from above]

Board: 2 copper layers, 115.0 x 80.0 mm, 15 parts (0 on the bottom side), 21 nets.

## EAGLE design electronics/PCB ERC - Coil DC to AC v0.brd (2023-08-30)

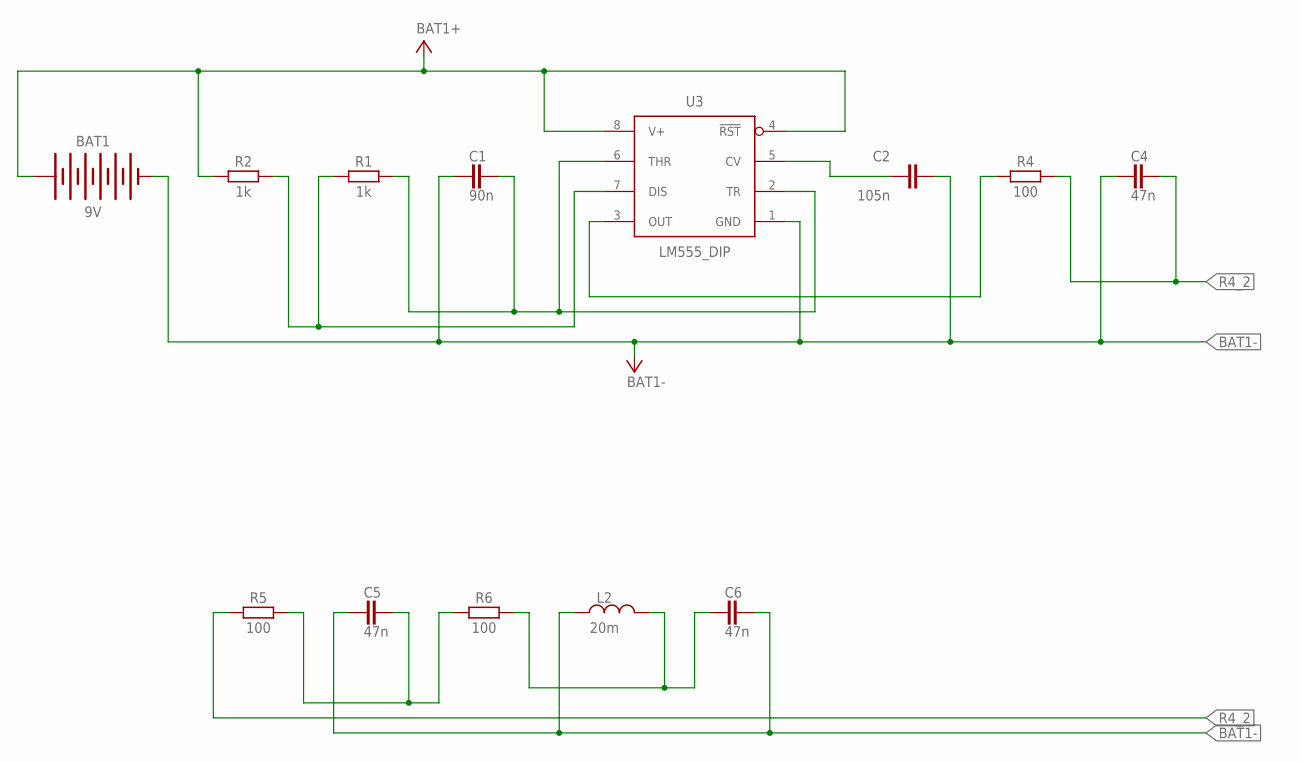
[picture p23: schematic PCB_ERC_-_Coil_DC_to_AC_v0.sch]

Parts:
BAT1: 9V; BATTERY-GENERIC
C1: 90n; CAP-THRU-2.54MM
C2: 105n; CAP-THRU-2.54MM
C4, C5, C6: 47n; CAP-THRU-2.54MM
L2: 20m; INDRD2743W50D3810H2616B
R1, R2: 1k; RESAD1016W63L850D250B
R4, R5, R6: 100; RESAD1016W63L850D250B
U3: LM555_DIP; DIP826W53P254L959H508Q8B

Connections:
BAT1+: BAT1.+, R2.2, U3.4 (!RST), U3.8 (V+)
BAT1-: BAT1.-, C1.2, C2.2, C4.2, C5.2, C6.1, L2.1, U3.1 (GND)
R4_2: C4.1, R4.2, R5.1
R5_2: C5.1, R5.2, R6.1
R6_2: C6.2, L2.2, R6.2
U3_CV: C2.1, U3.5 (CV)
U3_DIS: R1.2, R2.1, U3.7 (DIS)
U3_OUT: R4.1, U3.3 (OUT)
U3_THR: C1.1, R1.1, U3.2 (TR), U3.6 (THR)

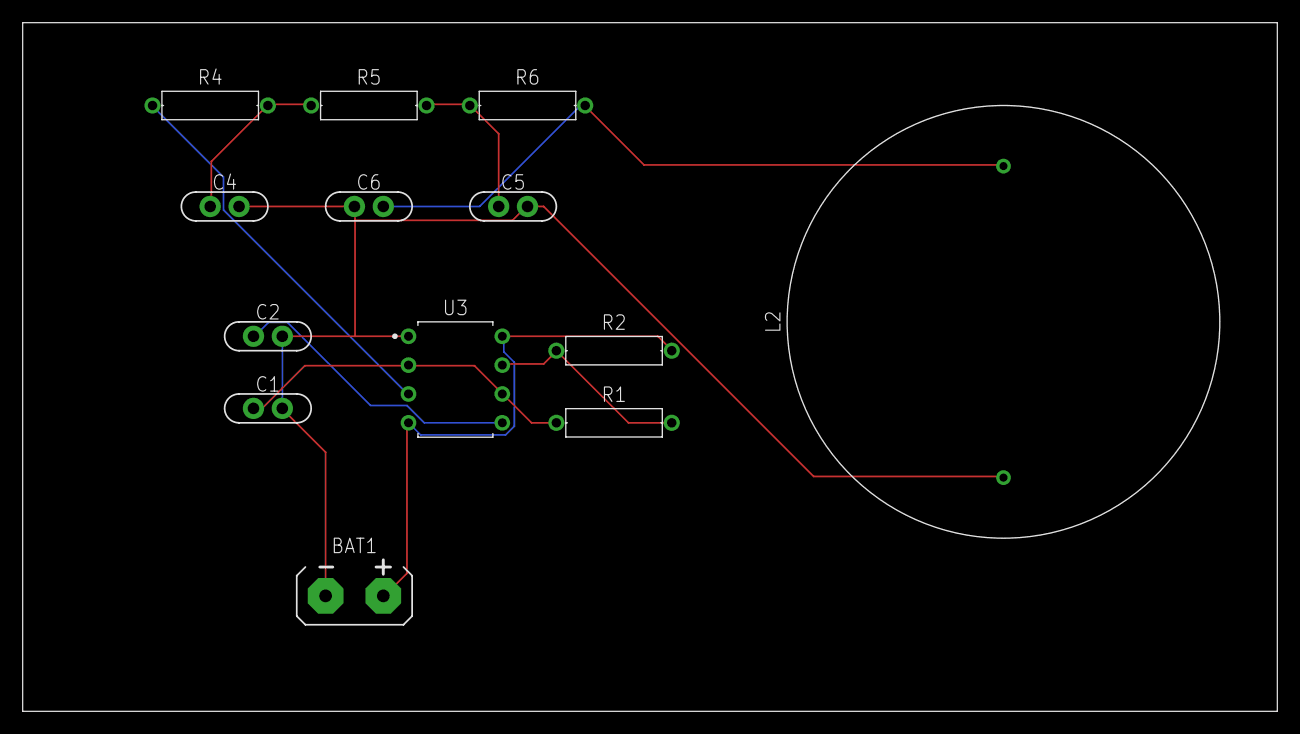
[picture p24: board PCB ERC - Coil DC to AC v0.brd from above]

Board: 2 copper layers, 110.5 x 60.6 mm, 13 parts (0 on the bottom side), 9 nets.

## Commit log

2023-08-27 added an array of points which T3 follows but it doesnt work, due to overshoot and all, so will have to implement good pid controll
2023-08-27 entirely went around maze perfectly no pid control though, just simple instructions
2023-08-27 stupid try to improve path planning, as currently moves very robotic
2023-08-29 low battery commit
2023-08-30 added electronics
    [PCB ERC - Coil DC to AC v0.brd, PCB ERC - Coil DC to AC v0.f3d, PCB ERC - Control (3-7).brd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]
